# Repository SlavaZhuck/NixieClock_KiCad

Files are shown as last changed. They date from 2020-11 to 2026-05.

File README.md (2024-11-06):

# Clock on gas-discharge Nixie indicators  "IN-14" and Arduino
A fork of the adm503 project for those who want to be able to make changes to the circuit and/or board layout.
The circuit is copied with minimal changes (resistors, diode and transistor are changed to smd). The board and circuit are implemented in KiCad for 6 IN-14 lamps.<br>
The board has not been assembled and tested. It may not be. Please consider this information when using.<br>
The firmware has been updated to work with the DS3231M clock module.
The ability to automatically display data from the pressure, humidity and temperature sensor has been added.

Controls:
- When displaying the clock:
- M (double click) - enter the time settings mode;
- (hold) - enter the alarm settings mode;
- "minus" (short) - switches the lamp backlight modes;
- (hold) - enables/disables "glitches";
- "plus" (short) - switches the digit scrolling modes;
- (hold) - auto show temperature, pressure and humidity measurements
- sensor (short) - show temperature, pressure, humidity, set alarm time
(only if the alarm is on) and return to the clock display mode;
- (hold) - the same as (short).

- When the alarm goes off (a melody plays):
- sensor (short) - reset the signal, the alarm remains on;
- sensor (hold) - reset the signal, the alarm remains on.

- When displaying temperature, humidity, pressure, alarm time:
- sensor (short) - switch to the next parameter (pressure, humidity, set alarm time, clock display);
- (hold) - return to the clock display mode;

- When setting the time:
- M (short) - switch between setting hours and minutes;
- (hold) - reset the current group of digits to 00;
- "minus" (short) - decrease the value;
- (hold) - decrease the value by 5;
- "plus" (short) - increase the value;
- (hold) - increase the value by 5;
- sensor (short) - exit saving the settings;
- sensor (hold) - exit returning to the previous value.

- When setting the alarm:
- M (short) - switch between setting hours and minutes;
- (hold) - reset the current group of digits to 00;
- "minus" (short) - decrease the value;
- (hold) - decrease the value by 5;
- "plus" (short) - increase the value;
- (hold) - increase the value by 5;
- sensor (short) - exit with saving settings;
- sensor (hold) - turn on/off the alarm.

- Effects IN CLOCK MODE:
- Backlight (color changes cyclically: red, green, blue):
- Breathing;
- Constant glow;
- Disabled.
- Change digits (during change, the effect number is briefly displayed in all digits):
- (0) No effect;
- (1) Smooth fading;
- (2) Rewind in numerical order;
- (3) Rewind by cathodes;
- (4) Train;
- (5) Rubber band.
- The behavior of the second dot depends on whether the alarm is on? is set by the parameters:
- DOT_IN_TIME - when the alarm is off;
- DOT_IN_ALARM - when the alarm is on.
The dot behavior can be selected from the following values:
- DM_NULL, (0) the dot is always off;
- DM_ONCE, (1) the dot blinks once a second (normal);
- DM_HALF, (2) the dot changes brightness once a second;
- DM_TWICE, (3) the dot blinks twice a second;
- DM_THREE, (4) the dot blinks three times a second;
- DM_FULL, (5) the dot is always on

# Часы на газоразрядных индикаторах "ИН-14" и Arduino
Форк проекта adm503 для желающих иметь возможность сделать изменения в схеме и\или разводке платы.
Схема скопирована с минимальными изменениями (резисторы, диод и транзистор изменены на smd). Плата и схема реализованы в KiCad для 6-ти ламп ИН-14.<br>
Плата не была собрана и проверена. Возможно и не будет. Учитывайте пожалуйста эту информацию при использовании. <br>

Была обновлена прошивка для работы с модулем часов DS3231M.
Добавлена возможность автоматического показания данных с сенсора давления, влажности и температуры.
Управление:
  Управление:
  - При отображении часов:
    - М       (двойной клик) - войти в режим настроек времени;
    -         (удержание) - войти в режим настроек будильника;
    - "минус" (кратко) - переключает режимы подсветки ламп;
    -         (удержание) - включает/отключает "глюки";
    - "плюс"  (кратко) - переключает режимы перелистывания цифр;
    -         (удержание) - автопоказывать измерения температуры, давления и влажности
    - сенсор  (кратко) - показать температуру, давление, влажность, установленное время будильника
              (только если будильник включен) и вернуться в режим отображения часов;
    -         (удержание) - то же, что (кратко).
    
  - При срабатывании будильника (играет мелодия):
    - сенсор  (кратко) - сброс сигнала, будильник остаётся включенным;
    - сенсор  (удержание) - сброс сигнала, будильник остаётся включенным.
    
  - При демонстрации температуры, влажности, давлении, времени будильника:
    - сенсор  (кратко) - переключиться на следующий параметр (давление, влажность, установленное
              время будильника, отображение часов);
    -         (удержание) - вернуться в режим отображения часов;
    
  - При настройке времени:
    - М       (кратко) - переключение между установкой часов и минут;
    -         (удержание) - сброс текущей группы разрядов в 00;
    - "минус" (кратко) - уменьшение значения;
    -         (удержание) - уменьшение значения на 5;
    - "плюс"  (кратко) - увеличение значения;
    -         (удержание) - уведичение значения на 5;
    - сенсор  (кратко) - выход с сохранением установок;
    - сенсор  (удержание) - выход с возвратом к прежнему значению.
    
  - При настройке будильника:
    - М       (кратко) - переключение между установкой часов и минут;
    -         (удержание) - сброс текущей группы разрядов в 00;
    - "минус" (кратко) - уменьшение значения;
    -         (удержание) - уменьшение значения на 5;
    - "плюс"  (кратко) - увеличение значения;
    -         (удержание) - уведичение значения на 5;
    - сенсор  (кратко) - выход с сохранением установок;
    - сенсор  (удержание) - включение/выключение будильника.
    
  - Эффекты В РЕЖИМЕ ЧАСОВ:
    - Подсветка (циклически изменяется цвет: красный,  зелёный, синий):
      - Дыхание;
      - Постоянное свечение;
      - Отключена.
    - Смена цифр (при смене на короткое время отображается номер эффекта во всех разрядах):
      - (0) Без эффекта;
      - (1) Плавное угасание;
      - (2) Перемотка по порядку числа;
      - (3) Перемотка по катодам;
      - (4) Поезд;
      - (5) Резинка.
    - Поведение секундной точки зависит от того, включен ли будильник? устанавливается параметрами:
      - DOT_IN_TIME - когда будильник выключен;
      - DOT_IN_ALARM - когда будильник включен.
      Выбор поведения точки можно осуществлять из следующих величин:
      - DM_NULL, (0) точка постоянно выключена;
      - DM_ONCE, (1) точка моргает один раз в секунду (штатно);
      - DM_HALF, (2) точка изменяет яркость раз в секунду;
      - DM_TWICE,(3) точка моргает два раза в секунду;
      - DM_THREE,(4) точка моргает три раза в секунду;
      - DM_FULL, (5) точка постоянно включена

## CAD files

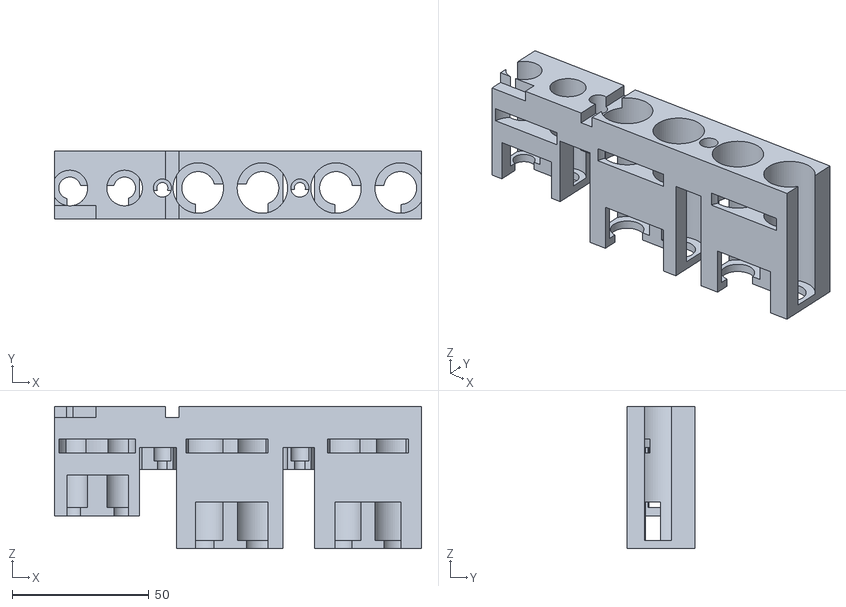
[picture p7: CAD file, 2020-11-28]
3D Print/Шаблон для монтажа ламп ИН-14 ИН-16.stl
134.0 x 25.0 x 52.0

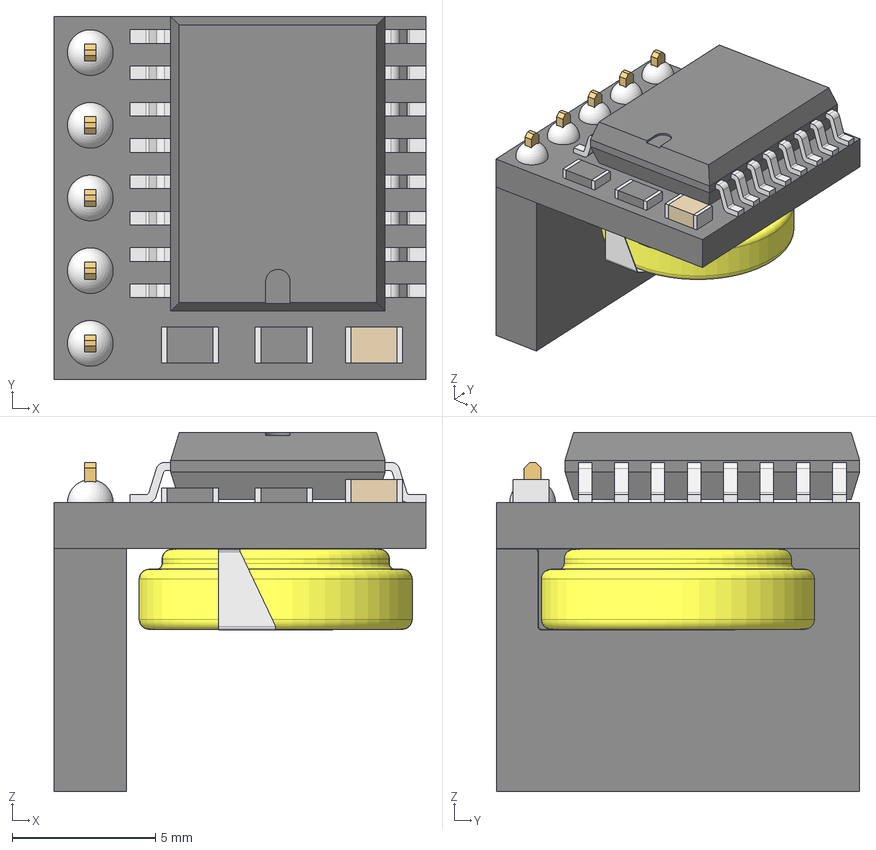
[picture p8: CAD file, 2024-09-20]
KiCad_project/KiCad_libs/3d_models/ds3231-real-time-clock-module-1/DS3231 Module.step
13.0 x 12.7 x 12.6 mm
Board_001
5 Pos Socket Header_001
SOIC16_001
0805 Resistor_001
0805 Resistor_002
0805 Capacitor_001
Battery_001

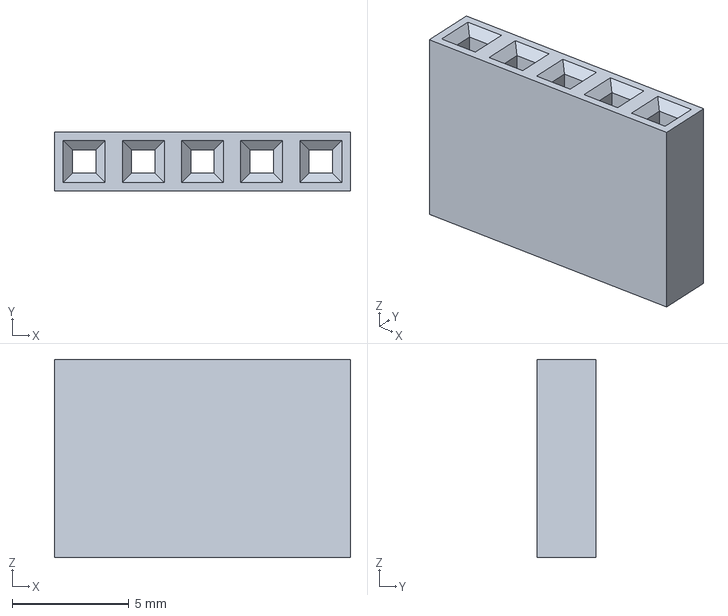
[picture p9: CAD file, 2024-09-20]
KiCad_project/KiCad_libs/3d_models/ds3231-real-time-clock-module-1/FreeCAD Files/5 Pos Socket Header.FCStd
12.7 x 2.54 x 8.50 mm

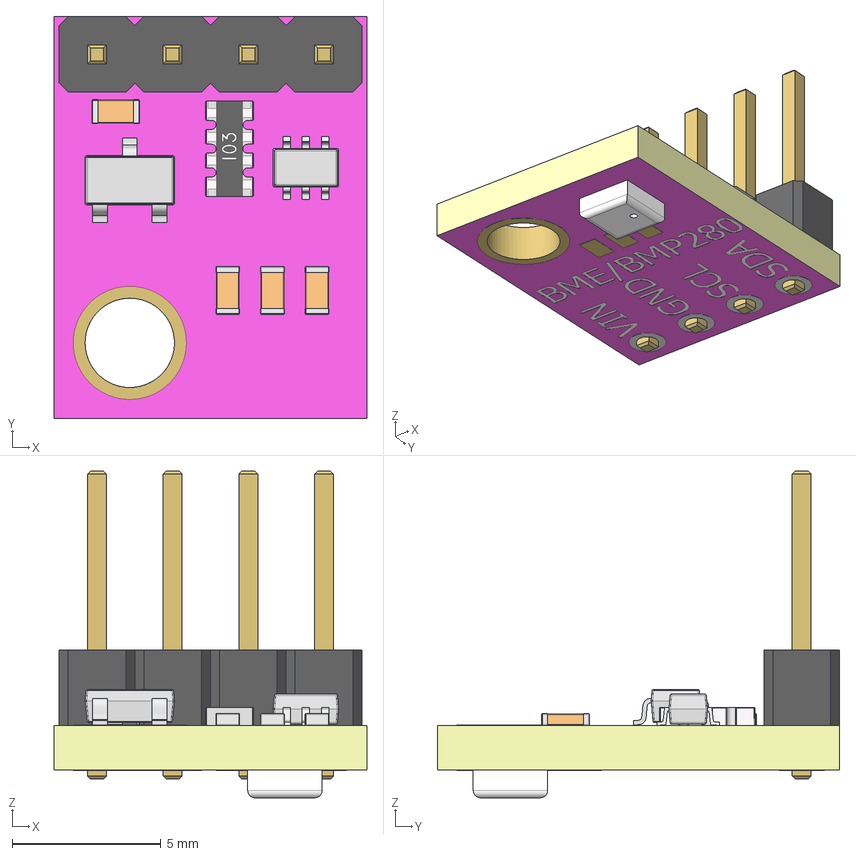
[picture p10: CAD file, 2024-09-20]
KiCad_project/KiCad_libs/3d_models/Sensor BME280.stp
10.5 x 13.5 x 11.0 mm
плата датчика BME280
SOT-363
PLS-4
Сборка 0805 4x
SOT23-3

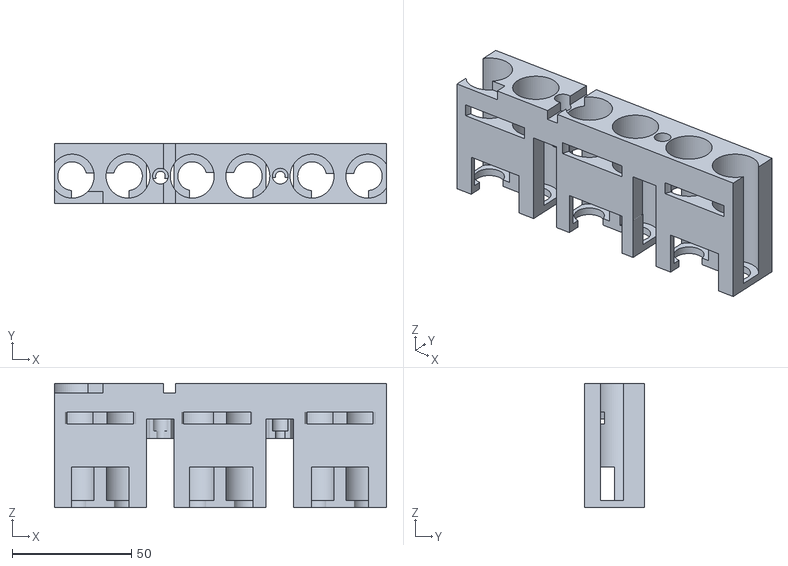
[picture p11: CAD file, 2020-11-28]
3D Print/Шаблон для монтажа ИН-14 х 6шт.stl
139.1 x 25.0 x 52.0

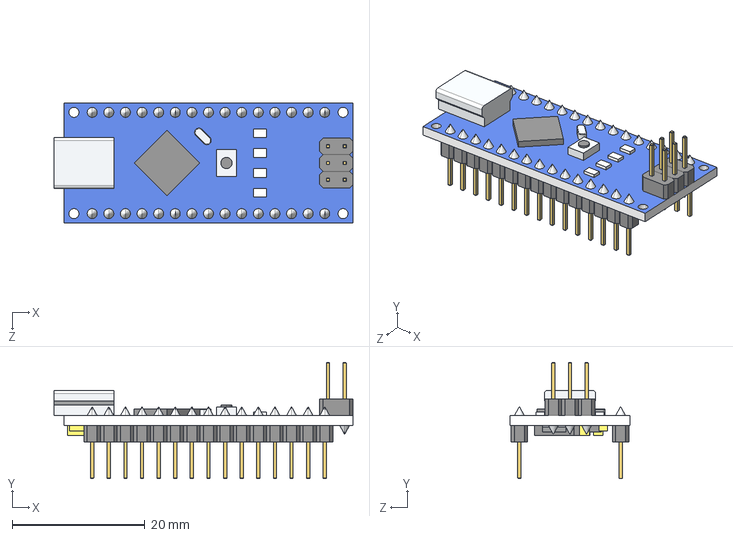
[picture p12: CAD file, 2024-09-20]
KiCad_project/KiCad_libs/3d_models/Arduino_Nano.STEP
45.0 x 17.5 x 18.0 mm

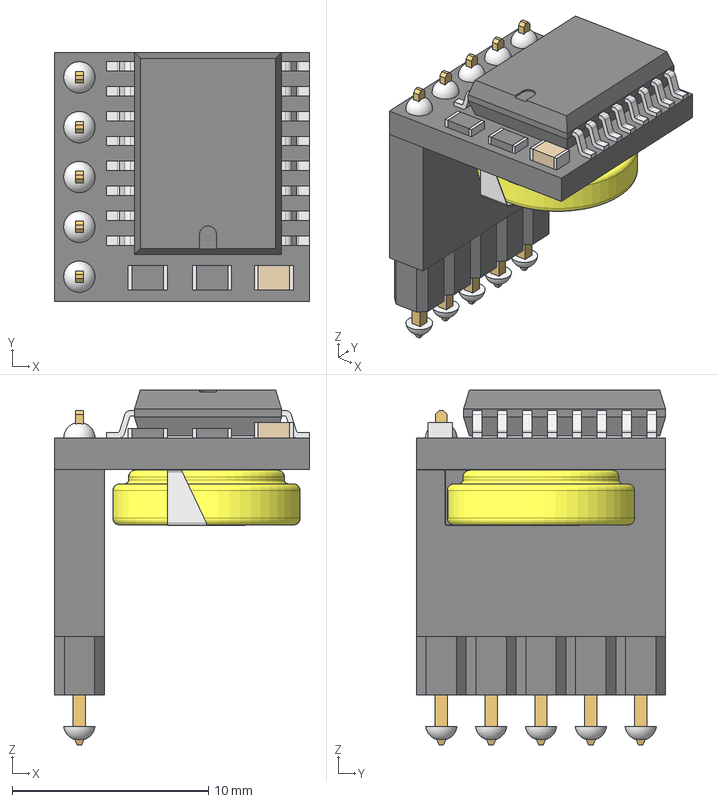
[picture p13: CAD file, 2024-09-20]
KiCad_project/KiCad_libs/3d_models/ds3231-real-time-clock-module-1/DS3231 Module With Header.step
13.0 x 12.7 x 18.1 mm
Board_001
5 Pos Socket Header_001
SOIC16_001
0805 Resistor_001
0805 Resistor_002
0805 Capacitor_001
Battery_001
1x5 Male Header_001

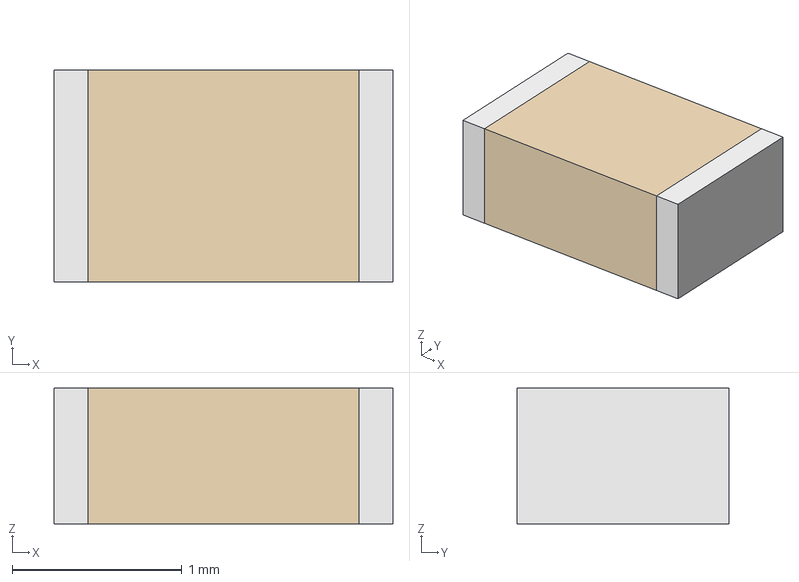
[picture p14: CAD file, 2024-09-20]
KiCad_project/KiCad_libs/3d_models/ds3231-real-time-clock-module-1/FreeCAD Files/0805 Capacitor.FCStd
2.00 x 1.25 x 0.8 mm
Body001 (Mirror #1)

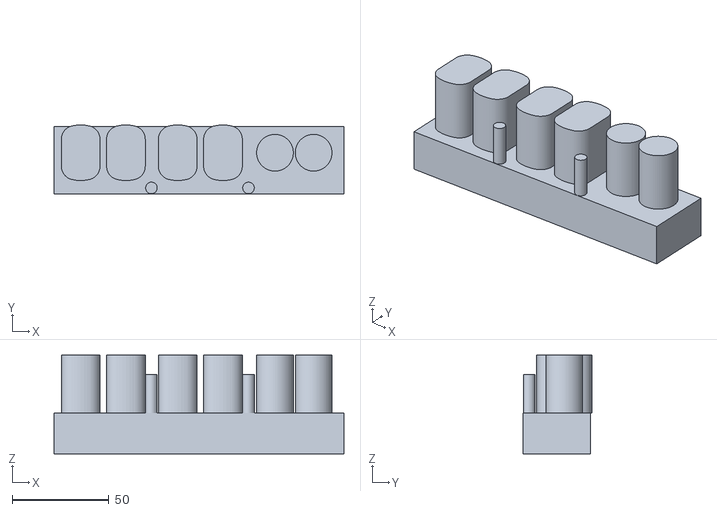
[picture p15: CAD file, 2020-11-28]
3D Print/Балванка для облепливания ИН-12.stl
150.0 x 35.8 x 51.0

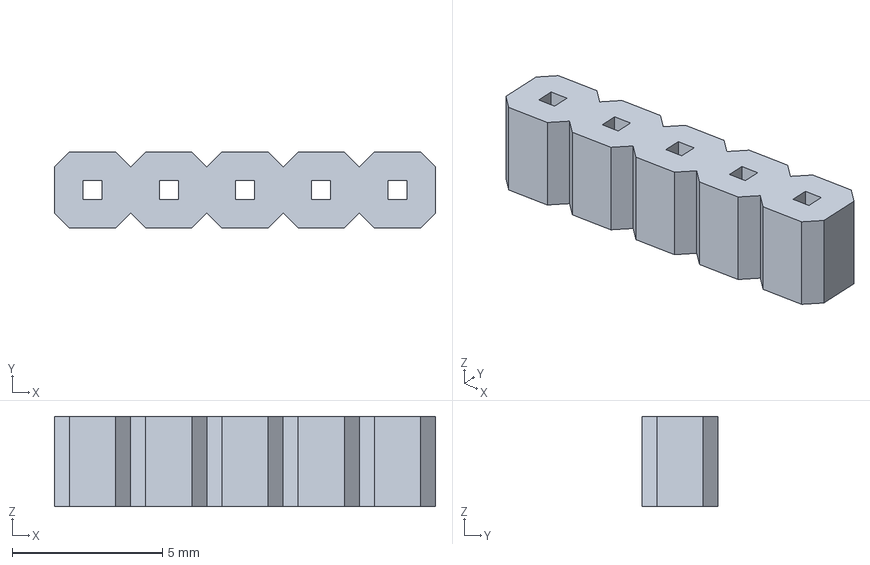
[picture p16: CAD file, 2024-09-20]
KiCad_project/KiCad_libs/3d_models/ds3231-real-time-clock-module-1/FreeCAD Files/1x5 Male Header.FCStd
12.7 x 2.54 x 3.00 mm

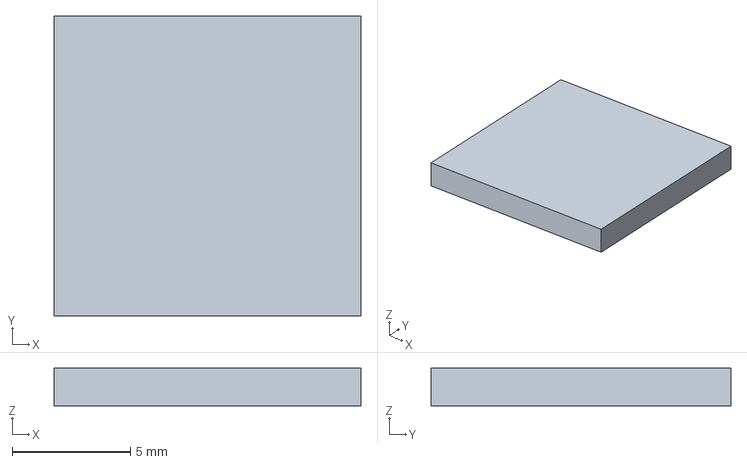
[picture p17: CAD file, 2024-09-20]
KiCad_project/KiCad_libs/3d_models/ds3231-real-time-clock-module-1/FreeCAD Files/Board.FCStd
13.0 x 12.7 x 1.60 mm

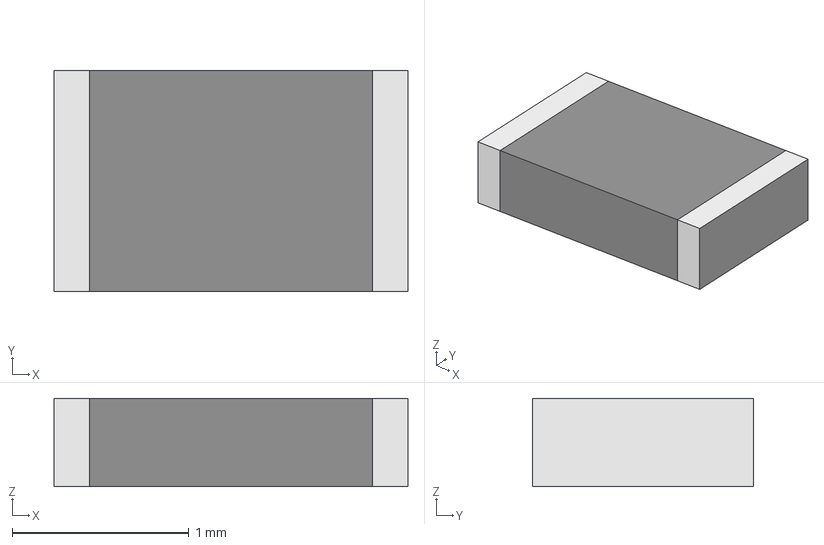
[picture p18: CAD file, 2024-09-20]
KiCad_project/KiCad_libs/3d_models/ds3231-real-time-clock-module-1/FreeCAD Files/0805 Resistor.FCStd
2.00 x 1.25 x 0.5 mm
Body001 (Mirror #1)

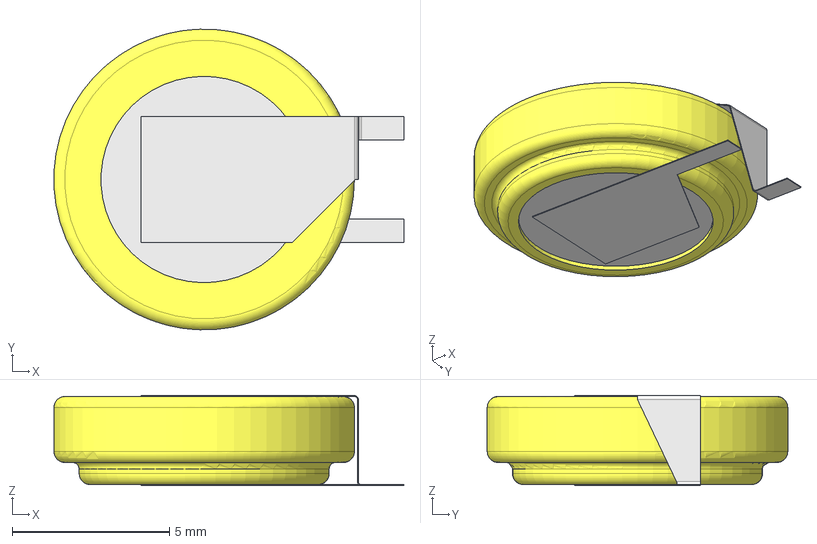
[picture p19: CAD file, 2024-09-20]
KiCad_project/KiCad_libs/3d_models/ds3231-real-time-clock-module-1/FreeCAD Files/Battery.FCStd
11.1 x 9.55 x 2.86 mm

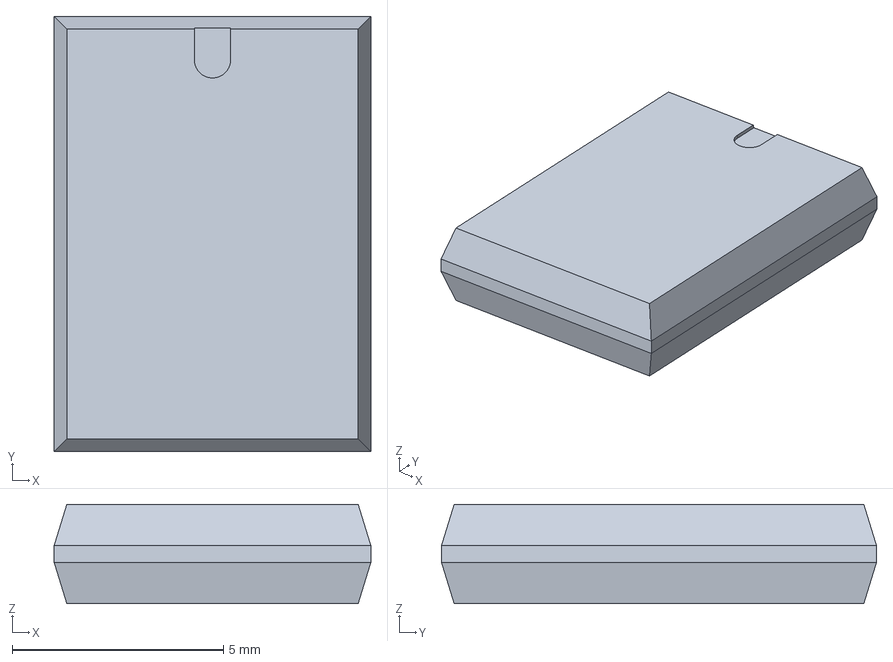
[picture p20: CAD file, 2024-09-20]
KiCad_project/KiCad_libs/3d_models/ds3231-real-time-clock-module-1/FreeCAD Files/SOIC16.FCStd
7.50 x 10.3 x 2.35 mm

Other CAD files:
KiCad_project/KiCad_libs/3d_models/Arduino_Nano.SLDPRT
KiCad_project/KiCad_libs/3d_models/ds3231-real-time-clock-module-1/FreeCAD Files/DS3231 Module.FCStd

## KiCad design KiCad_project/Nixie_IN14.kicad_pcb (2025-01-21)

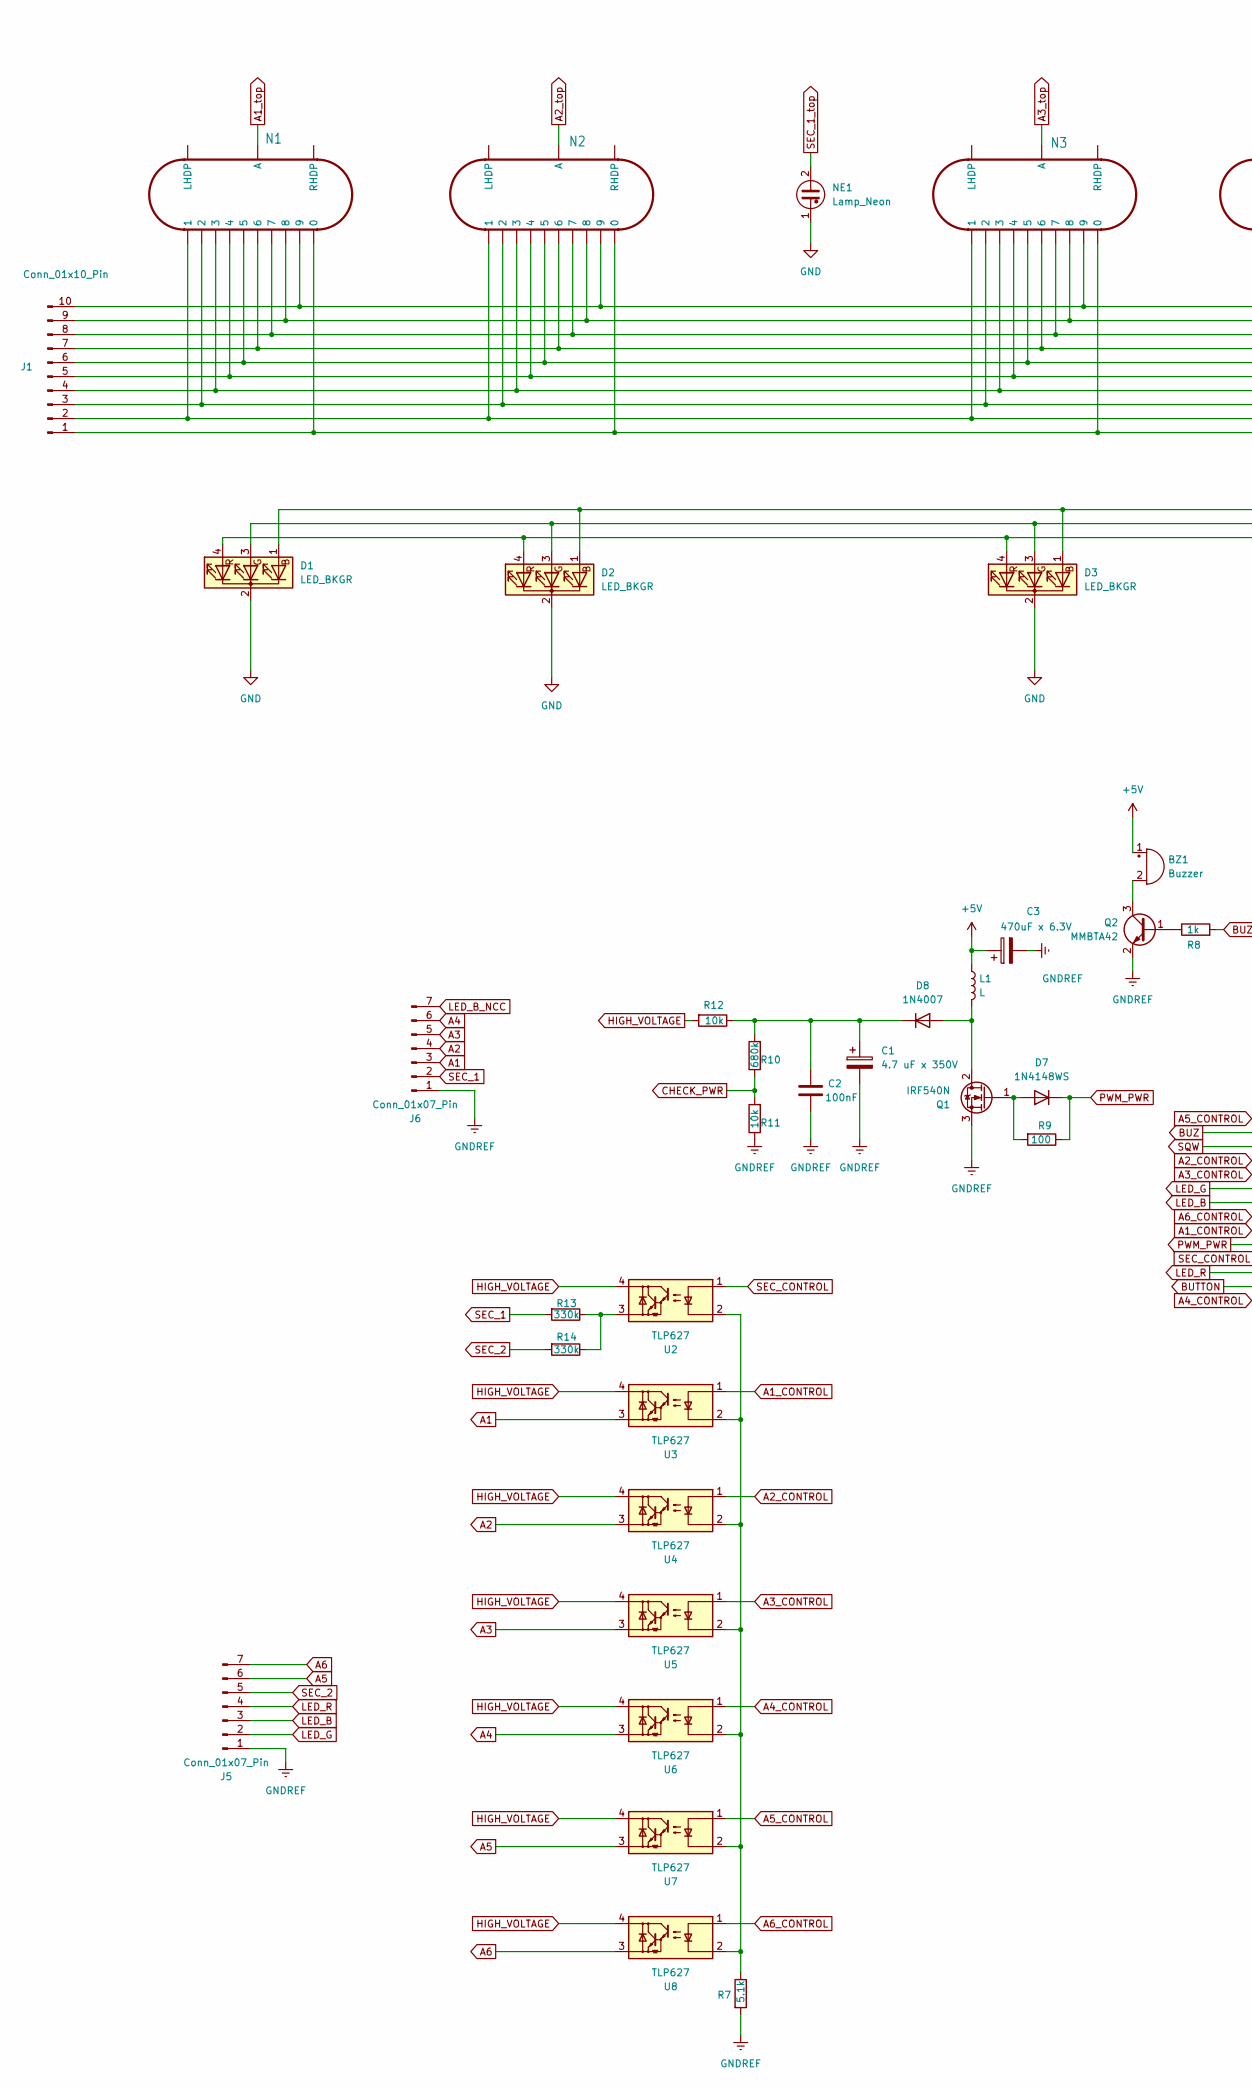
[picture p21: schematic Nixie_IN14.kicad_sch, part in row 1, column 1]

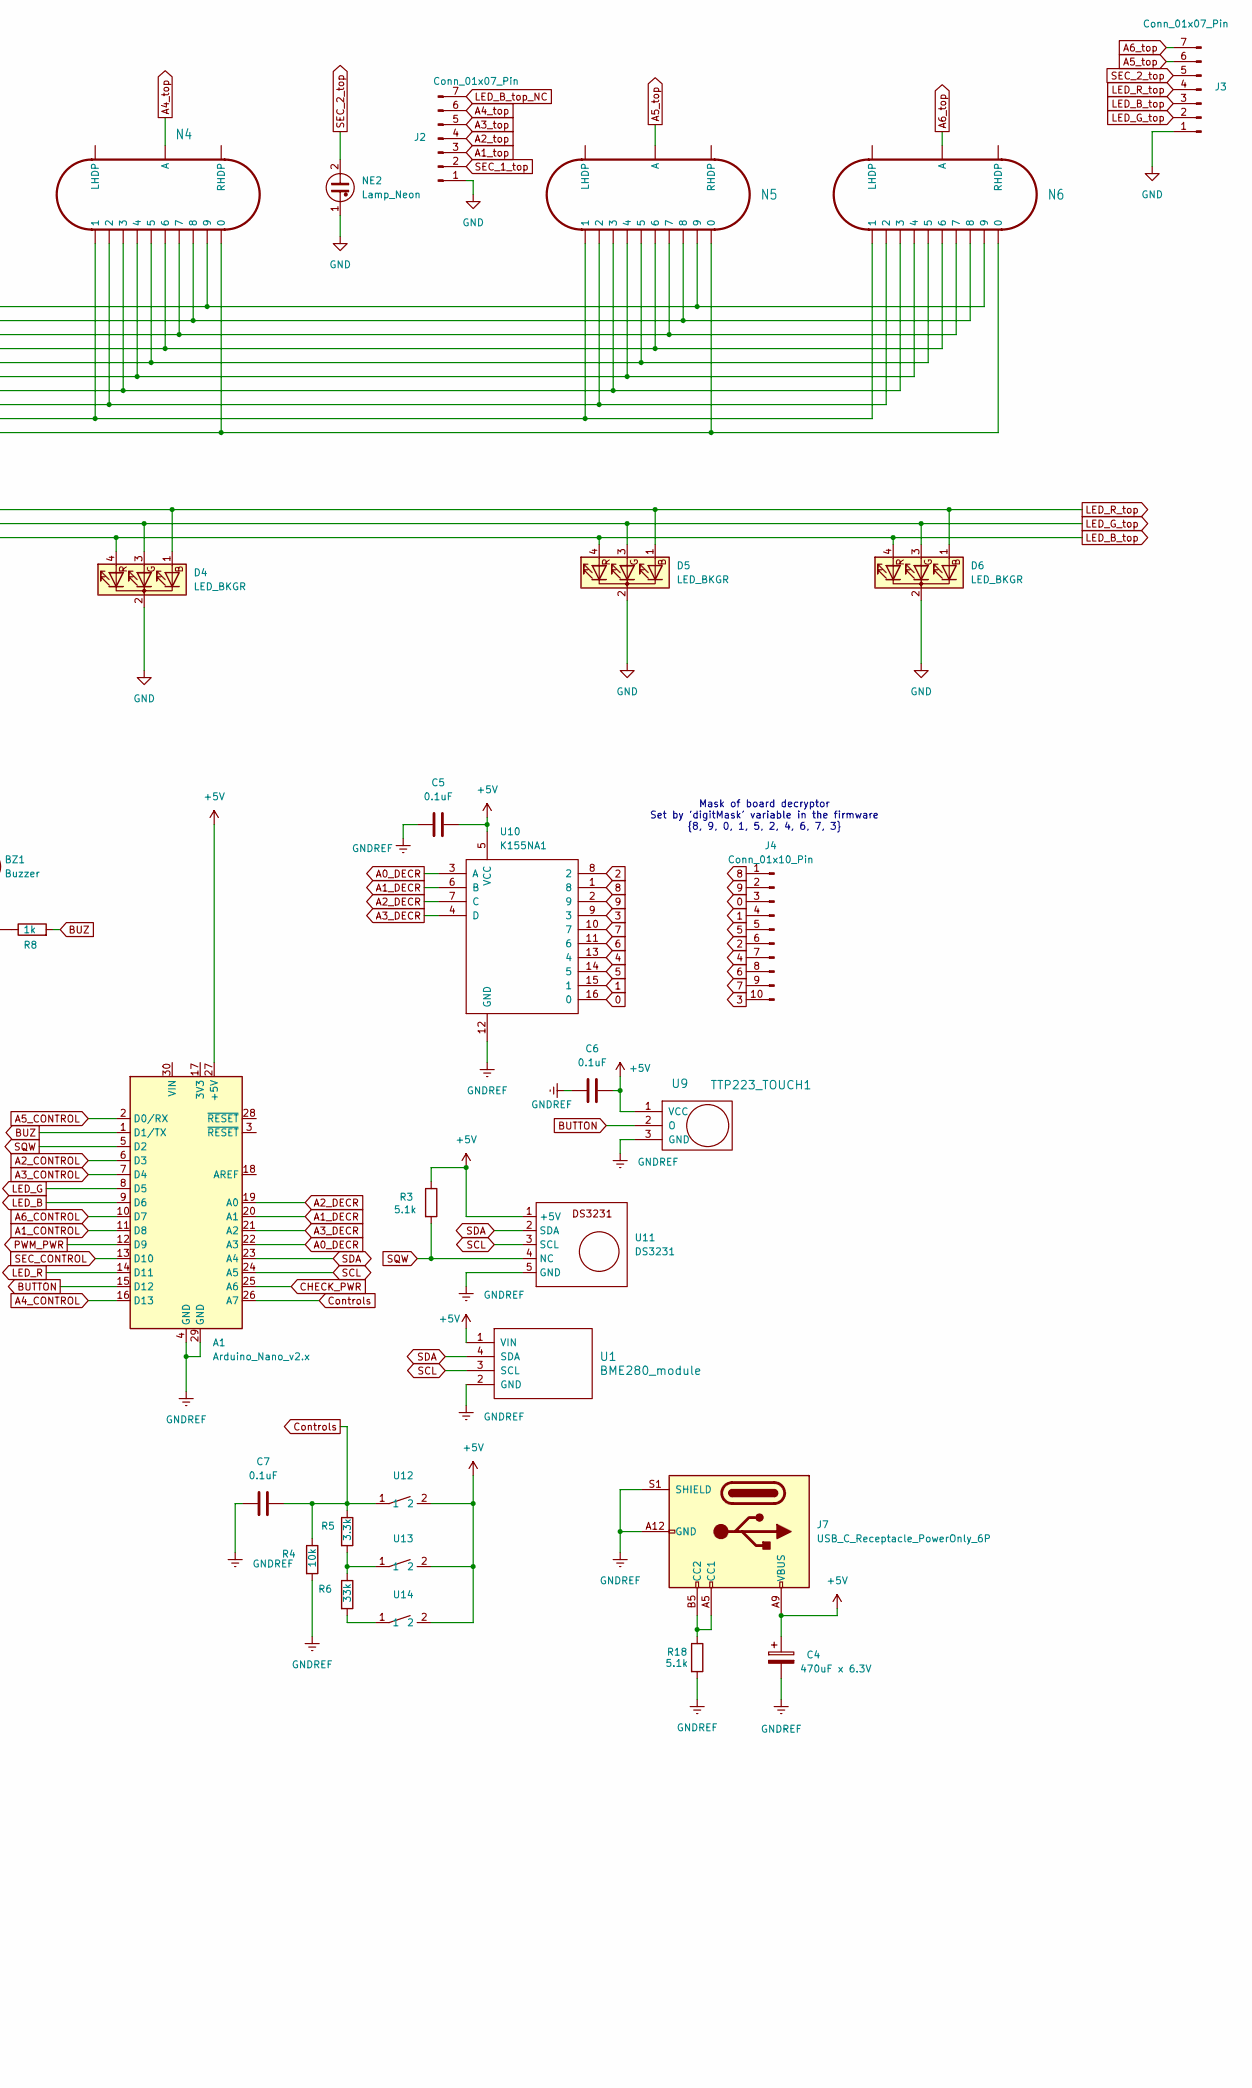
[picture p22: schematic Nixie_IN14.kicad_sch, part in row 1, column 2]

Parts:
A1: Arduino_Nano_v2.x; Arduino_Nano
BZ1: Buzzer; Buzzer_TDK_PS1240P02BT_D12.2mm_H6.5mm
C1: 4.7 uF x 350V; CP_Radial_D10.0mm_P2.50mm_P5.00mm
C2: 100nF; C_Rect_L10.0mm_W5.0mm_P5.00mm_P7.50mm
C3, C4: 470uF x 6.3V; CP_Radial_D5.0mm_P2.50mm
C5, C6, C7: 0.1uF; C_1206_3216Metric
D1, D2, D3, D4, D5, D6: LED_BKGR; LED_D5.0mm-4_RGB
D7: 1N4148WS; D_SOD-323
D8: 1N4007; D_DO-41_SOD81_P7.62mm_Horizontal
J1: Conn_01x10_Pin; PinSocket_1x10_P2.54mm_Vertical
J2, J3: Conn_01x07_Pin; PinSocket_1x07_P2.54mm_Vertical
J4: Conn_01x10_Pin; PinHeader_1x10_P2.54mm_Vertical
J5, J6: Conn_01x07_Pin; PinHeader_1x07_P2.54mm_Vertical
J7: USB_C_Receptacle_PowerOnly_6P; USB_C_Receptacle_HRO_TYPE-C-31-M-17
L1: L; L_Radial_D10.0mm_P5.00mm_Fastron_07M
N1, N2, N3, N4, N5, N6: IN-14
NE1, NE2: Lamp_Neon; NE2-NEON-BULB-DRILL
Q1: IRF540N; TO-220-3_Vertical
Q2: MMBTA42; SOT-23
R3, R7, R18: 5.1k; R_1206_3216Metric_Pad1.30x1.75mm_HandSolder
R4, R11, R12: 10k; R_1206_3216Metric_Pad1.30x1.75mm_HandSolder
R5: 3.3k; R_1206_3216Metric_Pad1.30x1.75mm_HandSolder
R6: 33k; R_1206_3216Metric_Pad1.30x1.75mm_HandSolder
R8: 1k; R_1206_3216Metric_Pad1.30x1.75mm_HandSolder
R9: 100; R_1206_3216Metric_Pad1.30x1.75mm_HandSolder
R10: 680k; R_1206_3216Metric_Pad1.30x1.75mm_HandSolder
R13, R14: 330k; R_1206_3216Metric_Pad1.30x1.75mm_HandSolder
U1: BME280_module
U2, U3, U4, U5, U6, U7, U8: TLP627; DIP-4_W7.62mm
U9: TTP223_TOUCH1; PinHeader_1x03_P2.54mm_Vertical
U10: K155NA1; DIP-16_W7.62mm
U11: DS3231; DS3231_PI
U12, U13, U14: my_button

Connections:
0: J4.3, U10.16 (0)
1: J4.4, U10.15 (1)
2: J4.6, U10.8 (2)
3: J4.10, U10.9 (3)
4: J4.7, U10.13 (4)
5: J4.5, U10.14 (5)
6: J4.8, U10.11 (6)
7: J4.9, U10.10 (7)
8: J4.1, U10.1 (8)
9: J4.2, U10.2 (9)
+5V: A1.27 (+5V), BZ1.1 (+), C3.1, C4.1, C5.2, C6.2, J7.A9 (VBUS), J7.B9 (VBUS), L1.1, R3.1, U1.1 (VIN), U9.1 (VCC), U10.5 (VCC), U11.1 (+5V), U12.2, U13.2, U14.2
A0_DECR: A1.22 (A3), U10.3 (A)
A1: J6.3, U3.3
A1_CONTROL: A1.11 (D8), U3.1
A1_DECR: A1.20 (A1), U10.6 (B)
A1_top: J2.3, N1.A
A2: J6.4, U4.3
A2_CONTROL: A1.6 (D3), U4.1
A2_DECR: A1.19 (A0), U10.7 (C)
A2_top: J2.4, N2.A
A3: J6.5, U5.3
A3_CONTROL: A1.7 (D4), U5.1
A3_DECR: A1.21 (A2), U10.4 (D)
A3_top: J2.5, N3.A
A4: J6.6, U6.3
A4_CONTROL: A1.16 (D13), U6.1
A4_top: J2.6, N4.A
A5: J5.6, U7.3
A5_CONTROL: A1.2 (D0/RX), U7.1
A5_top: J3.6, N5.A
A6: J5.7, U8.3
A6_CONTROL: A1.10 (D7), U8.1
A6_top: J3.7, N6.A
BUTTON: A1.15 (D12), U9.2 (O)
BUZ: A1.1 (D1/TX), R8.2
CHECK_PWR: A1.25 (A6), R10.1, R11.2
Controls: A1.26 (A7), C7.1, R4.1, R5.1, U12.1
GND: D1.2 (K), D2.2 (K), D3.2 (K), D4.2 (K), D5.2 (K), D6.2 (K), J2.1, J3.1, NE1.1, NE2.1
GNDREF: A1.4 (GND), A1.29 (GND), C1.2, C2.2, C3.2, C4.2, C5.1, C6.1, C7.2, J5.1, J6.1, J7.A12 (GND), J7.B12 (GND), J7.S1 (SHIELD), Q1.3 (S), Q2.2 (E), R4.2, R7.2, R11.1, R18.2, U1.2 (GND), U9.3 (GND), U10.12 (GND), U11.5 (GND)
HIGH_VOLTAGE: R12.2, U2.4, U3.4, U4.4, U5.4, U6.4, U7.4, U8.4
LED_B: A1.9 (D6), J5.3
LED_B_NCC: J6.7
LED_B_top: D1.4 (RA), D2.4 (RA), D3.4 (RA), D4.4 (RA), D5.4 (RA), D6.4 (RA), J3.3
LED_B_top_NC: J2.7
LED_G: A1.8 (D5), J5.2
LED_G_top: D1.3 (GA), D2.3 (GA), D3.3 (GA), D4.3 (GA), D5.3 (GA), D6.3 (GA), J3.2
LED_R: A1.14 (D11), J5.4
LED_R_top: D1.1 (BA), D2.1 (BA), D3.1 (BA), D4.1 (BA), D5.1 (BA), D6.1 (BA), J3.4
unnamed: BZ1.2 (-), Q2.3 (C)
unnamed: D7.2 (A), Q1.1 (G), R9.2
unnamed: D8.2 (A), L1.2, Q1.2 (D)
unnamed: C1.1, C2.1, D8.1 (K), R10.2, R12.1
unnamed: J1.1, N1.0, N2.0, N3.0, N4.0, N5.0, N6.0
unnamed: J1.2, N1.1, N2.1, N3.1, N4.1, N5.1, N6.1
unnamed: J1.3, N1.2, N2.2, N3.2, N4.2, N5.2, N6.2
unnamed: J1.4, N1.3, N2.3, N3.3, N4.3, N5.3, N6.3
unnamed: J1.5, N1.4, N2.4, N3.4, N4.4, N5.4, N6.4
unnamed: J1.6, N1.5, N2.5, N3.5, N4.5, N5.5, N6.5
unnamed: J1.7, N1.6, N2.6, N3.6, N4.6, N5.6, N6.6
unnamed: J1.8, N1.7, N2.7, N3.7, N4.7, N5.7, N6.7
unnamed: J1.9, N1.8, N2.8, N3.8, N4.8, N5.8, N6.8
unnamed: J1.10, N1.9, N2.9, N3.9, N4.9, N5.9, N6.9
unnamed: J7.A5 (CC1), J7.B5 (CC2), R18.1
unnamed: Q2.1 (B), R8.1
unnamed: R5.2, R6.1, U13.1
unnamed: R6.2, U14.1
unnamed: R7.1, U2.2, U3.2, U4.2, U5.2, U6.2, U7.2, U8.2
unnamed: R13.1, R14.1, U2.3
PWM_PWR: A1.12 (D9), D7.1 (K), R9.1
SCL: A1.24 (A5), U1.3 (SCL), U11.3 (SCL)
SDA: A1.23 (A4), U1.4 (SDA), U11.2 (SDA)
SEC_1: J6.2, R13.2
SEC_1_top: J2.2, NE1.2
SEC_2: J5.5, R14.2
SEC_2_top: J3.5, NE2.2
SEC_CONTROL: A1.13 (D10), U2.1
SQW: A1.5 (D2), R3.2, U11.4 (NC)

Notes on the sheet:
Mask of board decryptor Set by 'digitMask' variable in the firmware {8, 9, 0, 1, 5, 2, 4, 6, 7, 3}

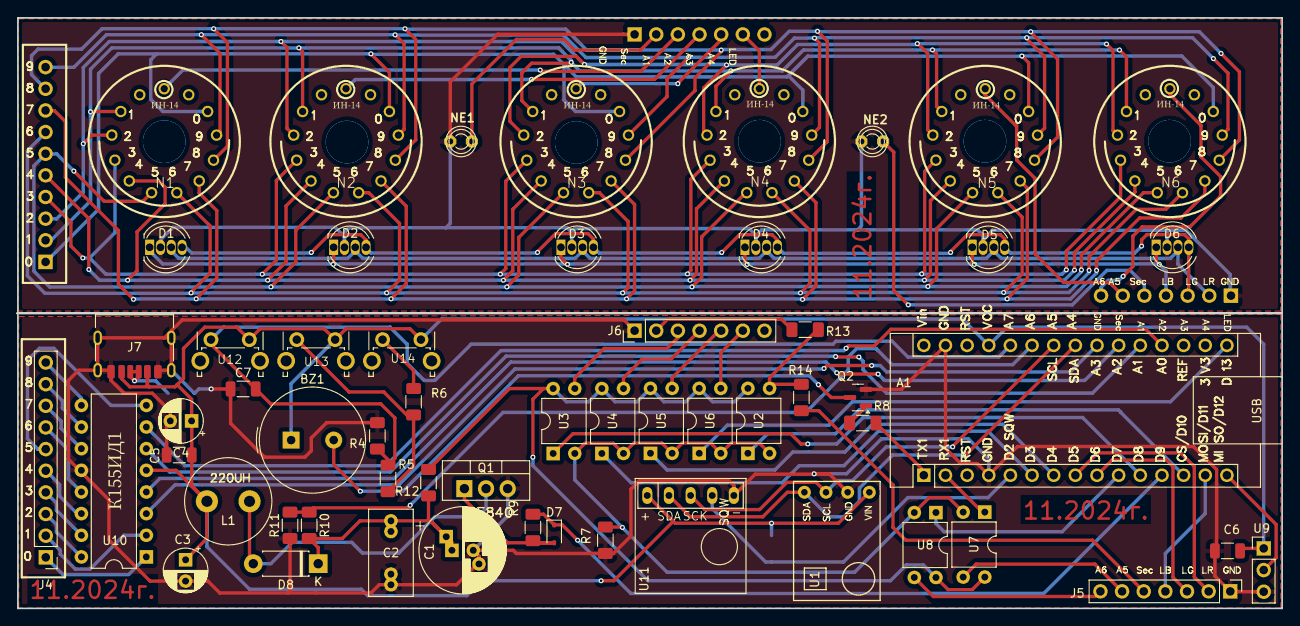
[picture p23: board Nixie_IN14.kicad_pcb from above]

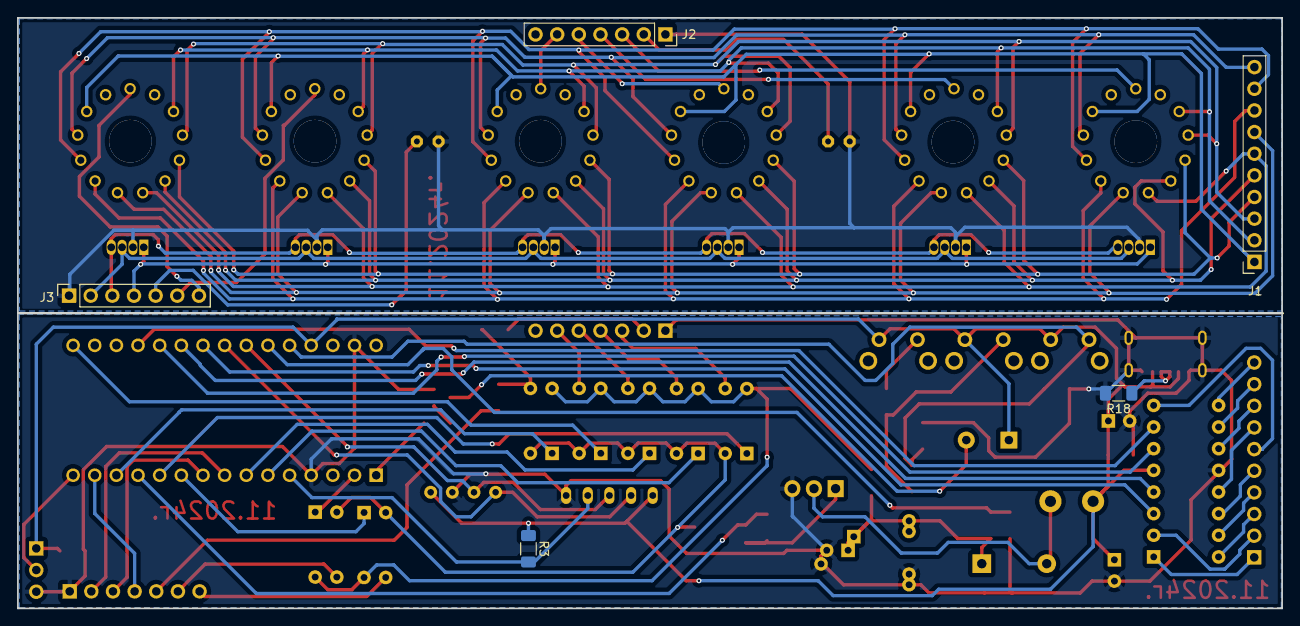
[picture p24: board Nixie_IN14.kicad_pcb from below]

Board: 2 copper layers, 148.3 x 69.3 mm, 62 parts (5 on the bottom side), 75 nets.

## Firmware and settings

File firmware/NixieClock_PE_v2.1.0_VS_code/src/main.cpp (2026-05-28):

/*
  main.cpp — точка входа Arduino sketch, основной цикл и определения
  глобальных объектов/переменных.

  Файл унаследовал стандартный шаблон Arduino main.cpp (Arduino Team, 2005-2013, LGPL 2.1).
*/

#include "NixieClock_PE_v2.1.0.h"
#include "timer2Minim.h"
#include <GyverButton.h>
#include <Wire.h>
#include <RTClib.h>
#include <Adafruit_BME280.h>

#include "effects.h"
#include "buttons.h"
#include "calculate_time.h"
#include "setup.h"
#include "set_time.h"
#include "DCDC.h"
#include "brightness.h"
#include "RTC_handler.h"
#include "global_externs.h"
#include "glitch.h"

// ==========================================================================
//  Периферия (определения; объявления — в peripherals_ext.h)
// ==========================================================================
RTC_DS3231 rtc;
Adafruit_BME280 bme;
Adafruit_Sensor *bme_temp     = bme.getTemperatureSensor();
Adafruit_Sensor *bme_pressure = bme.getPressureSensor();
Adafruit_Sensor *bme_humidity = bme.getHumiditySensor();
boolean isBMEhere;

GButton btnSet(BTN_NO_PIN, LOW_PULL, NORM_OPEN); // кнопка «М»
GButton btnL  (BTN_NO_PIN, LOW_PULL, NORM_OPEN); // кнопка «минус»
GButton btnR  (BTN_NO_PIN, LOW_PULL, NORM_OPEN); // кнопка «плюс»
GButton btnA  (ALARM_STOP, LOW_PULL, NORM_OPEN); // сенсорная кнопка

// ==========================================================================
//  Таймеры режимов
// ==========================================================================
byte flip_speed[] = {0, 60, 50, 40, 90, 90};
byte flip_effect_num = sizeof(flip_speed);

timerMinim flipTimer(flip_speed[flip_effect]); // таймер эффектов цифр
timerMinim glitchTimer(1000);                  // таймер «глюков»
timerMinim eshowTimer(300);                    // демонстрация номера эффекта
timerMinim autoTimer(ALARM_SH_TIME);           // автоматический выход из режимов
timerMinim measurementsTimer(MEASURE_PERIOD);  // обновление показаний BME
timerMinim autoShowMeasurementsTimer(0);       // автопоказ температуры/влажности/давления

// ==========================================================================
//  Состояние индикаторов
// ==========================================================================
volatile int8_t indiDimm[NUMTUB];   // величина диммирования (0-24)
volatile int8_t indiDigits[NUMTUB]; // отображаемые цифры (0-9)
byte newTime[NUMTUB];               // буфер новых значений для эффектов

byte anodeStates = 0x3F;            // битовая маска включённых разрядов
byte indiMaxBright = INDI_BRIGHT;
int  indiBrightCounter;

boolean newTimeFlag;
boolean newSecFlag;
boolean chBL = false;               // запрос обновления подсветки

// ==========================================================================
//  Время и синхронизация
// ==========================================================================
const unsigned int SQW_FREQ = 8192;    // ожидаемая частота SQW DS3231
volatile unsigned int SQW_counter = 0; // счётчик импульсов SQW
volatile boolean halfsecond = false;   // флаг прохождения полусекунды

int8_t hrs, mins, secs;
byte lastAdjustedMonth = 0;            // месяц последней автоподстройки (0 = не задано)
int8_t autoAdjustTimeValue = 0;        // поправка кварца, с/мес (−99…+99)
boolean monthAdjustPending = false;    // флаг: поправка обнаружена, ждём 30-й секунды

// ==========================================================================
//  Будильник
// ==========================================================================
int8_t alm_hrs, alm_mins;
boolean alm_set;
boolean alm_flag = ALARM_WAIT;

// ==========================================================================
//  Текущий режим и эффекты подсветки
// ==========================================================================
SH_MODES curMode = SHTIME;

byte backL_mode = 0;                // выбранный режим подсветки
byte backlColors[3] = {BACKLR, BACKLG, BACKLB};
byte backlColor;
boolean glitch_allowed = 1;
boolean auto_show_measurements = 1;
byte flip_effect = FM_SMOOTH;

static boolean showFlag = false;    // отображается номер эффекта при переходе

// ==========================================================================
//  Гамма-кривая для PWM (PROGMEM)
// ==========================================================================
static const uint8_t CRTgamma[256] PROGMEM = {
    0,   0,   1,   1,   1,   1,   1,   1,   1,   1,   1,   1,   1,   1,   1,   1,
    2,   2,   2,   2,   2,   2,   2,   2,   3,   3,   3,   3,   3,   3,   4,   4,
    4,   4,   4,   5,   5,   5,   5,   6,   6,   6,   7,   7,   7,   8,   8,   8,
    9,   9,   9,  10,  10,  10,  11,  11,  12,  12,  12,  13,  13,  14,  14,  15,
   15,  16,  16,  17,  17,  18,  18,  19,  19,  20,  20,  21,  22,  22,  23,  23,
   24,  25,  25,  26,  26,  27,  28,  28,  29,  30,  30,  31,  32,  33,  33,  34,
   35,  35,  36,  37,  38,  39,  39,  40,  41,  42,  43,  43,  44,  45,  46,  47,
   48,  49,  49,  50,  51,  52,  53,  54,  55,  56,  57,  58,  59,  60,  61,  62,
   63,  64,  65,  66,  67,  68,  69,  70,  71,  72,  73,  74,  75,  76,  77,  79,
   80,  81,  82,  83,  84,  85,  87,  88,  89,  90,  91,  93,  94,  95,  96,  98,
   99, 100, 101, 103, 104, 105, 107, 108, 109, 110, 112, 113, 115, 116, 117, 119,
  120, 121, 123, 124, 126, 127, 129, 130, 131, 133, 134, 136, 137, 139, 140, 142,
  143, 145, 146, 148, 149, 151, 153, 154, 156, 157, 159, 161, 162, 164, 165, 167,
  169, 170, 172, 174, 175, 177, 179, 180, 182, 184, 186, 187, 189, 191, 193, 194,
  196, 198, 200, 202, 203, 205, 207, 209, 211, 213, 214, 216, 218, 220, 222, 224,
  226, 228, 230, 232, 233, 235, 237, 239, 241, 243, 245, 247, 249, 251, 253, 255,
};

byte getPWM_CRT(byte val)
{
  return pgm_read_byte(&(CRTgamma[val]));
}

// ==========================================================================
//  Низкоуровневое управление пинами и аппаратным PWM
// ==========================================================================

/* Быстрое управление выходными пинами (аналог digitalWrite).
 * Принудительно отключает PWM на пинах с аппаратной поддержкой.
 */
void setPin(byte pin, byte x)
{
  switch (pin)
  { // отключить PWM (Compare-Output-Mode бит) на пине
  case 3:  bitClear(TCCR2A, COM2B1); break;
  case 5:  bitClear(TCCR0A, COM0B1); break;
  case 6:  bitClear(TCCR0A, COM0A1); break;
  case 9:  bitClear(TCCR1A, COM1A1); break;
  case 10: bitClear(TCCR1A, COM1B1); break;
  case 11: bitClear(TCCR2A, COM2A1); break;
  }

  x = (x != 0);
  if      (pin < 8)  bitWrite(PORTD, pin,      x);
  else if (pin < 14) bitWrite(PORTB, pin -  8, x);
  else if (pin < 20) bitWrite(PORTC, pin - 14, x);
}

/* Быстрое управление аппаратным PWM (аналог analogWrite).
 * Работает только на пинах с аппаратной поддержкой.
 */
void setPWM(byte pin, byte duty)
{
  if (duty == 0) { setPin(pin, LOW); return; }
  switch (pin)
  {
  case 3:  bitSet(TCCR2A, COM2B1); OCR2B = duty; break;
  case 5:  bitSet(TCCR0A, COM0B1); OCR0B = duty; break;
  case 6:  bitSet(TCCR0A, COM0A1); OCR0A = duty; break;
  case 9:  bitSet(TCCR1A, COM1A1); OCR1A = duty; break;
  case 10: bitSet(TCCR1A, COM1B1); OCR1B = duty; break;
  case 11: bitSet(TCCR2A, COM2A1); OCR2A = duty; break;
  }
}

// ==========================================================================
//  Стандартные функции Arduino main.cpp (weak)
// ==========================================================================
int atexit(void (* /*func*/)()) { return 0; }
void initVariant() __attribute__((weak));
void initVariant() {}
void setupUSB() __attribute__((weak));
void setupUSB() {}

// ==========================================================================
//  Основной цикл
// ==========================================================================
void loop()
{
  // полусекундный тик — ход времени и пересчёт зависящих от него величин
  if (halfsecond)
  {
    if (startup_delay) startup_delay--;
    calculateTime(&dotBrightFlag, &dotBrightDirection, &dotBrightCounter);
  }

  beeper();

  // пока показывается номер эффекта — приостанавливаем перелистывание цифр
  if (showFlag)
  {
    if (eshowTimer.isReady()) showFlag = false;
  }
  else if ((newSecFlag || newTimeFlag) && curMode == SHTIME)
  {
    flipTick();
  }

  dotBrightTick();
  backlBrightTick();
  if (glitch_allowed && curMode == SHTIME) glitchTick();
  buttonsTick(&showFlag, &SQW_counter, &chBL);
  DCDCTick();
}

int main(void)
{
  init();
  initVariant();
#if defined(USBCON)
  USBDevice.attach();
#endif
  setup();
  for (;;)
  {
    loop();
    if (serialEventRun) serialEventRun();
  }
  return 0;
}

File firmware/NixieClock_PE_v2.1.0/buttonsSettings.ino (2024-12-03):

/* Поведение отображаемых значений в режимах установки
 *  Входные параметры: нет
 *  Выходные параметры: нет
 */
inline void settingsTick() 
{
  if (curMode == SETTIME || curMode == SETALARM) 
  {
    if (curMode == SETALARM && !alm_set) 
    {          // мигать отображением времени будильника, если будильник не установлен
      if (!(anodeStates == 0 || anodeStates == 0xF)) anodeStates = 0;
      if (blinkTimer.isReady()) anodeStates ^= 0xF;
    } 
    else 
    {
      if (blinkTimer.isReady()) 
      {
        lampState = !lampState;
        if (lampState) anodeStates = 0xF;
        else if (!currentDigit) anodeStates = 0x0C;
        else anodeStates = 0x3; 
      }
    }
  }
}

/* Возврат к отображению времени
 *  Входные параметры: нет
 *  Выходные параметры: нет
 */
void retToTime() 
{
  curMode = SHTIME;

  anodeStates = 0x3F;
  sendTime(hrs, mins, secs);

  dotSetMode( alm_set ? DOT_IN_ALARM : DOT_IN_TIME );
  chBL = true;
}

/* Обработка нажатий кнопок
 *  Входные параметры: нет
 *  Выходные параметры: нет
 */



inline void buttonsTick() 
{

  btnA.tick();                                    // определение, нажата ли кнопка Alarm
  // сначала - особый вариант реагирования на кнопки в режиме сработавшего будильника
  if (alm_flag) 
  {
    if (btnA.isClick() || btnA.isHolded()) alm_flag = false;
    return;
  }

  int analog = analogRead(A7);                    // чтение нажатой кнопки
  btnSet.tick(analog <= 1023 && analog > 950);    // определение, нажата ли кнопка Set
  btnL.tick(analog <= 860 && analog > 450);       // определение, нажата ли кнопка Up
  btnR.tick(analog <= 380 && analog > 100);       // определение, нажата ли кнопка Down

  switch (curMode) 
  {
    /*------------------------------------------------------------------------------------------------------------------------------*/
    case SHTIME:                                  // (0) отображение часов
      if (btnR.isClick())                         // переключение эффектов цифр
      {                       
        if (++FLIP_EFFECT >= FLIP_EFFECT_NUM) FLIP_EFFECT = FM_NULL;
        EEPROM.put(FLIPEFF, FLIP_EFFECT);
                                                  // для показа номера эффекта
        eshowTimer.reset();
        showFlag = true;
        memset((void*)indiDimm, indiMaxBright, NUMTUB);
        memset((void*)indiDigits, FLIP_EFFECT, NUMTUB);

        anodeStates = 0x3F;
        newSecFlag = true;
 
        newTimeFlag = true;
      }
      
      if (btnR.isHolded()) // автопоказывать измерения температуры, давления и влажности
      {
        auto_show_measurements = !auto_show_measurements;
        EEPROM.put(AUTOSHOWMEAS, auto_show_measurements);
      }

      if (btnL.isClick())                           // переключение эффектов подсветки
      {                       
        if (++BACKL_MODE >= 3) 
        {
          BACKL_MODE = 0;
          digitalWrite(backlColors[backlColor], 0);
          if(++backlColor >= 3) backlColor = 0;
          EEPROM.put(BLCOLOR, backlColor);
        }
        EEPROM.put(LIGHTEFF, BACKL_MODE);
        chBL = true;
      }

      if (btnL.isHolded()) // переключение глюков
      {                      
        GLITCH_ALLOWED = !GLITCH_ALLOWED;
        EEPROM.put(GLEFF, GLITCH_ALLOWED);
      }
      
      if (btnA.isClick() 
          || 
          btnA.isHolded() 
          || 
          autoShowMeasurementsTimer.isReadyDisable() 
         ) // переход в режим отображения температуры
      {    
        curMode = SHTEMP;
        if (isBMEhere) 
        { 
          bme_temp->getEvent(&temp_event);
          bme_pressure->getEvent(&pressure_event);
          bme_humidity->getEvent(&humidity_event);
          indiDigits[0] = (byte)((int)temp_event.temperature / 10);
          indiDigits[1] = (byte)((int)temp_event.temperature % 10);
          indiDigits[2] = (byte)((int)(temp_event.temperature * 10) % 10); 
        } 
        else 
        {
          indiDigits[0] = (byte) 0;
          indiDigits[1] = (byte) 0;
          indiDigits[2] = (byte) 0; 
        }
        measurementsTimer.reset();
        anodeStates = 0x07;
        autoTimer.setInterval(TEMP_SH_TIME);
        autoTimer.reset();
        dotSetMode( DM_NULL );
        chBL = true;
      }
      
      if (btnSet.isDouble()) // переход в режим установки времени
      {                    
        anodeStates = 0x0F;
        currentDigit = false;
        curMode = SETTIME;
        changeHrs = hrs;
        changeMins = mins;
        sendTime(changeHrs, changeMins, 0);

        chBL = true;
      }

      if (btnSet.isHolded()) // переход в режим установки будильника и времени его
      {                   
        anodeStates = 0x0F;
        currentDigit = false;
        curMode = SETALARM;
        changeHrs = alm_hrs;
        changeMins = alm_mins;
        
        sendTime(changeHrs, changeMins, 0);

        dotSetMode( DM_NULL );
        chBL = true;
      }
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

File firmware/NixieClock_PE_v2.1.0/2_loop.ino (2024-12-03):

/* Структурная функция основного цикла
 *  Входные параметры: нет
 *  Выходные параметры: нет
 */


void loop() {


  if (halfsecond) calculateTime();                // каждые 500 мс пересчёт и отправка времени
  beeper();
  if (showFlag) 
  {                                 // отображение номера эффекта для цифр при переходе
    if(eshowTimer.isReady()) showFlag = false;
  } 
  else 
  {
    if ((newSecFlag || newTimeFlag) && curMode == 0) 
    {
      flipTick();     // перелистывание цифр
    }
  }
  dotBrightTick();                                // плавное мигание точки
  backlBrightTick();                              // плавное мигание подсветки ламп
  if (GLITCH_ALLOWED && curMode == SHTIME) glitchTick();  // глюки
  buttonsTick();                                  // кнопки
  settingsTick();                                 // настройки
  DCDCTick();                                     // анодное напряжение
}

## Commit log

2024-09-16 upload KiCad libraries PCB routing is not finished
    [Nixie_IN14.kicad_pcb, Nixie_IN14.kicad_sch]
2024-09-16 added missed power capacitors fixed some resistor values continue placing elements on the PCB
    [Nixie_IN14.kicad_pcb, Nixie_IN14.kicad_sch]
2024-09-17 continue placing components
    [Nixie_IN14.kicad_pcb, Nixie_IN14.kicad_sch]
2024-09-17 placing and routing update
    [Nixie_IN14.kicad_pcb, Nixie_IN14.kicad_sch]
2024-09-18 optimized placement for tracing added labels on schematic added capacitor for button
    [Nixie_IN14.kicad_pcb, Nixie_IN14.kicad_sch]
2024-09-18 updated placement started routing
    [Nixie_IN14.kicad_pcb, Nixie_IN14.kicad_sch]
2024-09-19 placeng update first version of tracing is finished
    [Nixie_IN14.kicad_pcb]
2024-09-19 optimized routing and placement
    [Nixie_IN14.kicad_pcb]
2024-09-19 optimized placement and routing
    [Nixie_IN14.kicad_pcb]
2024-09-20 increased via diameters for drilling, routing optimization
    [Nixie_IN14.kicad_pcb]
2024-09-20 added 3d models
    [0805 Capacitor.FCStd, 0805 Resistor.FCStd, 1x5 Male Header.FCStd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]
2024-09-21 fixed connection error replaced and rerouted
    [Nixie_IN14.kicad_pcb, Nixie_IN14.kicad_sch]
2024-09-22 minor routing optimization
    [Nixie_IN14.kicad_pcb]
2024-09-22 added power keys for LEDs resistor pacjakges changed from 0805 to 1206
    [Nixie_IN14.kicad_pcb, Nixie_IN14.kicad_sch]
2024-11-02 DS3231SN switched to DS3231M,
    left only type 3 board support
2024-11-02 added periodic autoshow measurements with control from R-button (hold to turn On-Off) with saving to EEPROM
2024-11-06 decreased Voltage to 170 Volts, minor changes of brightness. Changed synchro mechanism for dynamic indication
2024-11-08 git-annex in slava@slava-ThinkPad-E14-Gen-4-M:~/Documents/NixieClock_KiCad
    [0805 Capacitor.FCStd, 0805 Resistor.FCStd, 1x5 Male Header.FCStd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]
2024-11-08 restored broken commit = updated placing of Arduino on PCB, optimized routing
    [0805 Capacitor.FCStd, 0805 Resistor.FCStd, 1x5 Male Header.FCStd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]
2024-12-03 fixed compiler warnings updated time update process, each second data read from RTC updated auto show of measurements
    [0_data.ino, bright.ino, buttonsSettings.ino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]
2024-12-03 only refactoring of brackets
2024-12-04 fixed burnIndicator and brightness usage
    [timeTicker.ino]
2024-12-05 synchronized with Arduino project
2025-01-21 update dot night brightness. Updated PCB for previous commit
    [Nixie_IN14.kicad_pcb, Nixie_IN14.kicad_sch]
2025-01-21 fix dot brightness for night
    [NixieClock_PE_v2.1.0.h]
2025-02-02 fix formatting, no functional changes
    [DCDC.cpp, NixieClock_PE_v2.1.0.h, RTC_handler.cpp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]
2026-05-27 added time adjustment to compensate quartz drift. Added possibility to set year, day and month
    [NixieClock_PE_v2.1.0.h, main.cpp, setup.cpp]
2026-05-28 # What changed Where 1 SETALARM hours/minutes adjust collapsed into bumpAlarm(delta, editingMins); fixed the copy-paste bug where btnR.isClick() was used twice instead of btnR.isHolded() for the +5 c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
    [RTC_handler.cpp, main.cpp]
2026-05-28 refactoring fix double extraction of startup_delay
    [DCDC.cpp, brightness.cpp, main.cpp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]
